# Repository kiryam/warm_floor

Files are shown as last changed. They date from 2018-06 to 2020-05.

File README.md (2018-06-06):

# Absolutely no warranty USE ON YOUR OWN RISK

# About this project
This project I started when I finished my home lab in balcony of my house.
I found that it is very cold in december. I decided to install floor heater to make temperature comfortable,
but first attempt been wrong. I had very hot floor. I decided to make floor heater with 5 zones (unformattly right now device have support for 6 zones)

# Hardware
## High voltage module
todo

## Logic module
todo

## Controller module
todo

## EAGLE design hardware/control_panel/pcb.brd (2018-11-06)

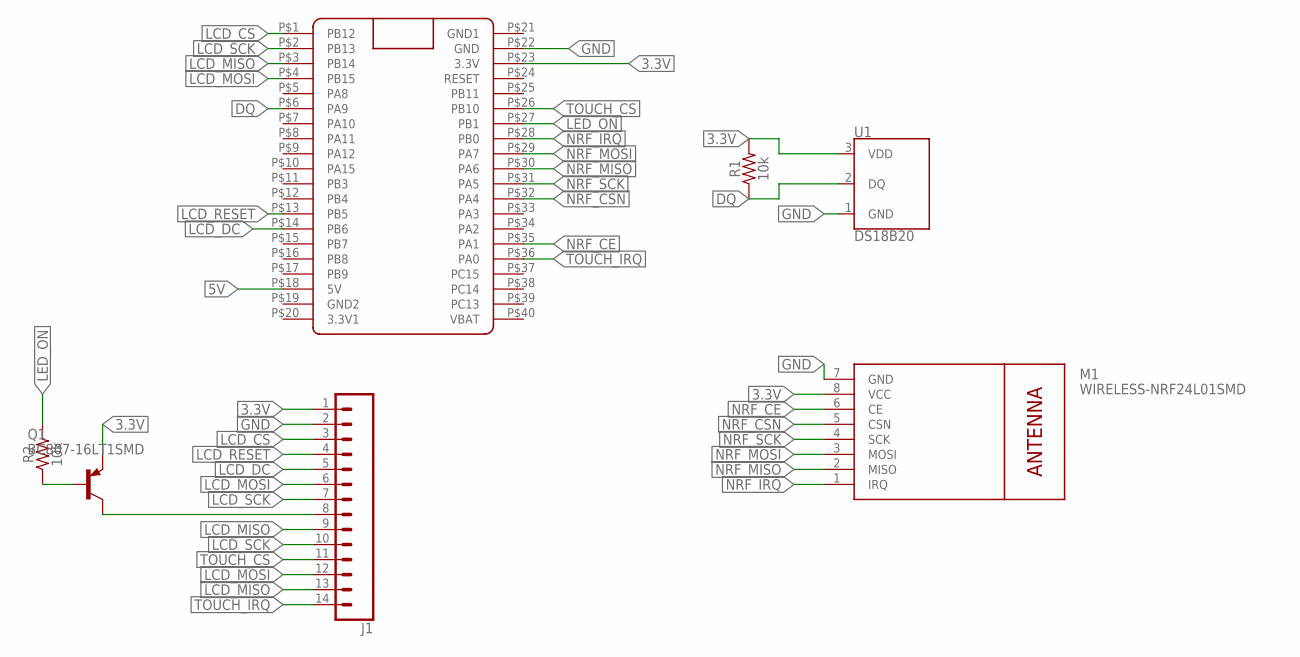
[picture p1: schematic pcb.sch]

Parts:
J1: CONN_14; 1X14
M1: WIRELESS-NRF24L01SMD; WIRELESS-NRF24L01-SMD
Q1: BC807-16LT1SMD; SOT23-BEC
R1, R2: 10k; 0603
U1: DS18B20; TO-92-AMMO
U$1: BLUE_PILL

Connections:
3.3V: J1.1, M1.8 (VCC), Q1.E, R1.2, U1.3 (VDD), U$1.P$23 (3.3V)
5V: U$1.P$18 (5V)
DQ: R1.1, U1.2 (DQ), U$1.P$6 (PA9)
GND: J1.2, M1.7 (GND), U1.1 (GND), U$1.P$22 (GND)
GND1: U$1.P$21 (GND1)
LCD_CS: J1.3, U$1.P$1 (PB12)
LCD_DC: J1.5, U$1.P$14 (PB6)
LCD_MISO: J1.9, J1.13, U$1.P$3 (PB14)
LCD_MOSI: J1.6, J1.12, U$1.P$4 (PB15)
LCD_RESET: J1.4, U$1.P$13 (PB5)
LCD_SCK: J1.7, J1.10, U$1.P$2 (PB13)
LED_ON: R2.2, U$1.P$27 (PB1)
unnamed: Q1.B, R2.1
unnamed: J1.8, Q1.C
NRF_CE: M1.6 (CE), U$1.P$35 (PA1)
NRF_CSN: M1.5 (CSN), U$1.P$32 (PA4)
NRF_IRQ: M1.1 (IRQ), U$1.P$28 (PB0)
NRF_MISO: M1.2 (MISO), U$1.P$30 (PA6)
NRF_MOSI: M1.3 (MOSI), U$1.P$29 (PA7)
NRF_SCK: M1.4 (SCK), U$1.P$31 (PA5)
TOUCH_CS: J1.11, U$1.P$26 (PB10)
TOUCH_IRQ: J1.14, U$1.P$36 (PA0)

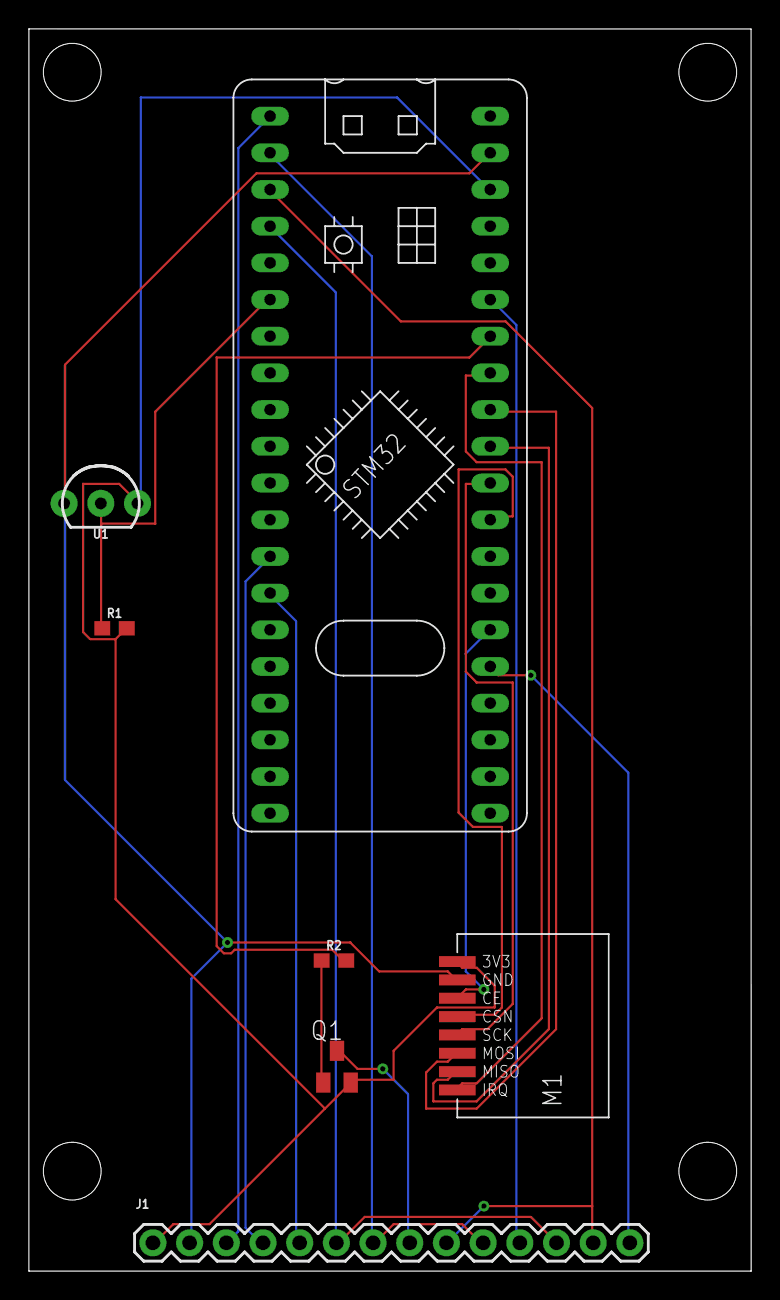
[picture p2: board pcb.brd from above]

Board: 2 copper layers, 50.0 x 86.0 mm, 7 parts (0 on the bottom side), 20 nets.

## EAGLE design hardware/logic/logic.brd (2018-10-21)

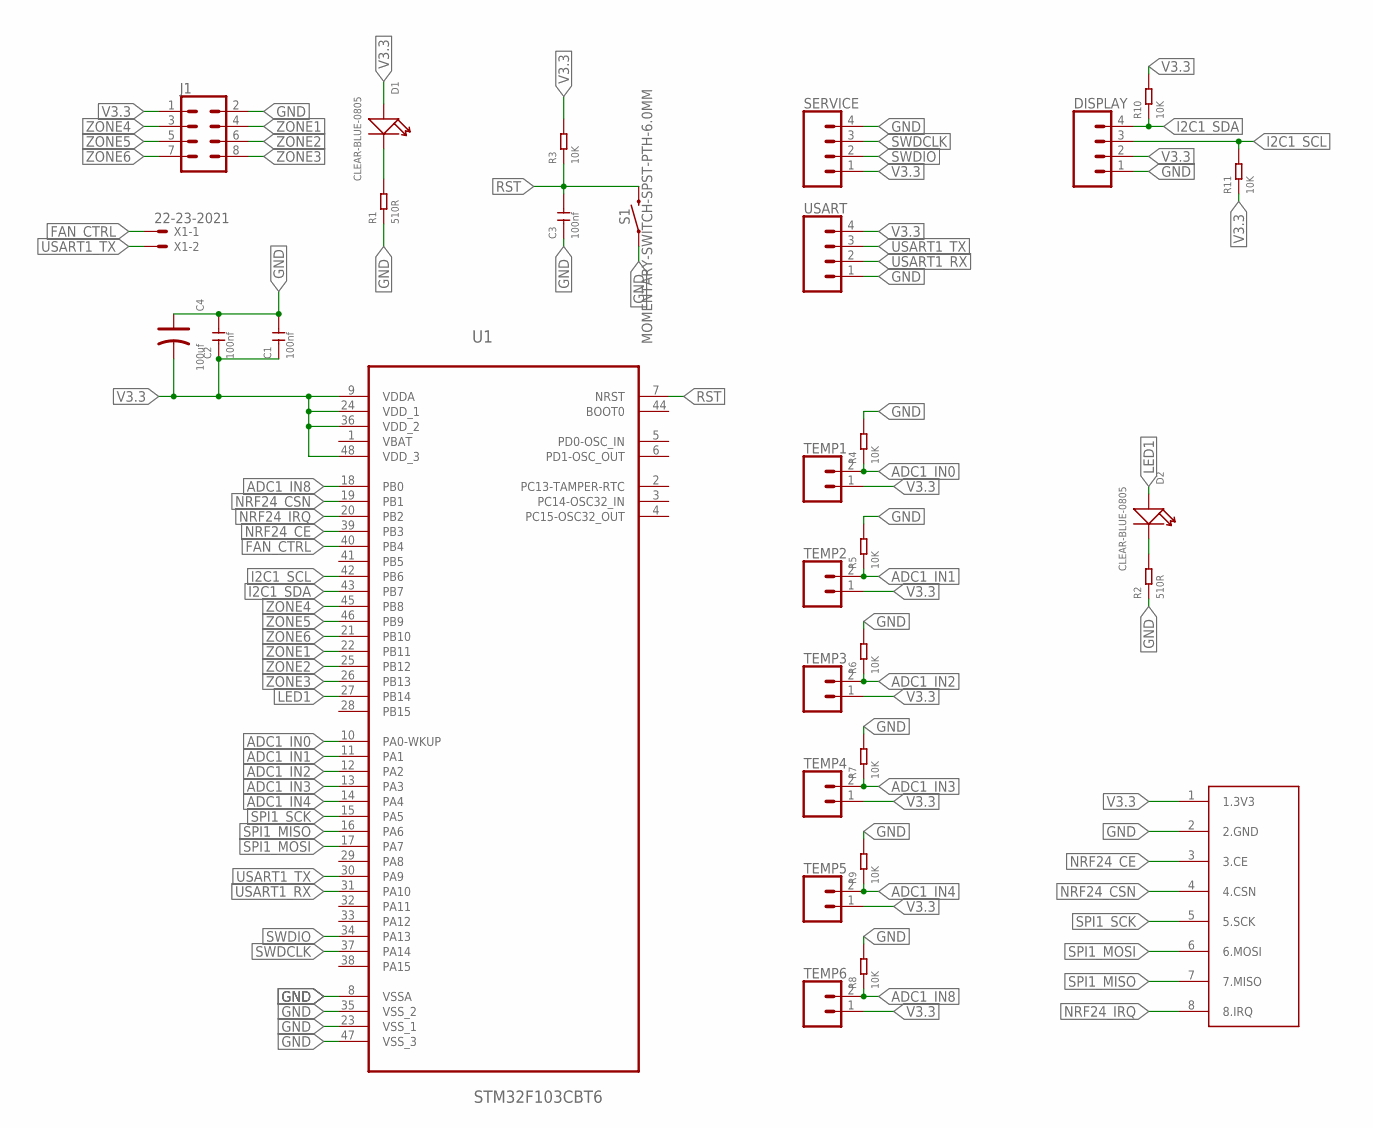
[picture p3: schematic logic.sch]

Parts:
C1, C2, C3: 100nf; C0805
C4: 100uf; AVX-B
D1, D2: CLEAR-BLUE-0805; LED-0805
DISPLAY: CONN_04; 1X04
J1: CONN_04X2; 2X4
R1, R2: 510R; R0603
R3, R4, R5, R6, R7, R8, R9, R10, R11: 10K; R0805
S1: MOMENTARY-SWITCH-SPST-PTH-6.0MM; TACTILE_SWITCH_PTH_6.0MM
SERVICE: CONN_04; 1X04
TEMP1, TEMP2, TEMP3, TEMP4, TEMP5, TEMP6: CONN_02; 1X02
U1: STM32F103CBT6; QFP50P900X900X160-48N
U$2: NRF24L01+
USART: CONN_04; 1X04
X1: 22-23-2021

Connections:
ADC1_IN0: R4.1, TEMP1.2, U1.10 (PA0-WKUP)
ADC1_IN1: R5.1, TEMP2.2, U1.11 (PA1)
ADC1_IN2: R6.1, TEMP3.2, U1.12 (PA2)
ADC1_IN3: R7.1, TEMP4.2, U1.13 (PA3)
ADC1_IN4: R9.1, TEMP5.2, U1.14 (PA4)
ADC1_IN8: R8.1, TEMP6.2, U1.18 (PB0)
FAN_CTRL: U1.40 (PB4), X1.1
GND: C1.2, C2.2, C3.1, C4.+, DISPLAY.1, J1.2, R1.1, R2.1, R4.2, R5.2, R6.2, R7.2, R8.2, R9.2, S1.1, SERVICE.4, U1.8 (VSSA), U1.23 (VSS_1), U1.35 (VSS_2), U1.47 (VSS_3), U$2.2 (2.GND), USART.1
I2C1_SCL: DISPLAY.3, R11.2, U1.42 (PB6)
I2C1_SDA: DISPLAY.4, R10.1, U1.43 (PB7)
LED1: D2.+, U1.27 (PB14)
unnamed: D1.-, R1.2
unnamed: D2.-, R2.2
NRF24_CE: U1.39 (PB3), U$2.3 (3.CE)
NRF24_CSN: U1.19 (PB1), U$2.4 (4.CSN)
NRF24_IRQ: U1.20 (PB2), U$2.8 (8.IRQ)
PA11: U1.32 (PA11)
RST: C3.2, R3.1, S1.3 (2), U1.7 (NRST)
SPI1_MISO: U1.16 (PA6), U$2.7 (7.MISO)
SPI1_MOSI: U1.17 (PA7), U$2.6 (6.MOSI)
SPI1_SCK: U1.15 (PA5), U$2.5 (5.SCK)
SWDCLK: SERVICE.3, U1.37 (PA14)
SWDIO: SERVICE.2, U1.34 (PA13)
USART1_RX: U1.31 (PA10), USART.2
USART1_TX: U1.30 (PA9), USART.3, X1.2
V3.3: C1.1, C2.1, C4.-, D1.+, DISPLAY.2, J1.1, R3.2, R10.2, R11.1, SERVICE.1, TEMP1.1, TEMP2.1, TEMP3.1, TEMP4.1, TEMP5.1, TEMP6.1, U1.9 (VDDA), U1.24 (VDD_1), U1.36 (VDD_2), U1.48 (VDD_3), U$2.1 (1.3V3), USART.4
ZONE1: J1.4, U1.22 (PB11)
ZONE2: J1.6, U1.25 (PB12)
ZONE3: J1.8, U1.26 (PB13)
ZONE4: J1.3, U1.45 (PB8)
ZONE5: J1.5, U1.46 (PB9)
ZONE6: J1.7, U1.21 (PB10)

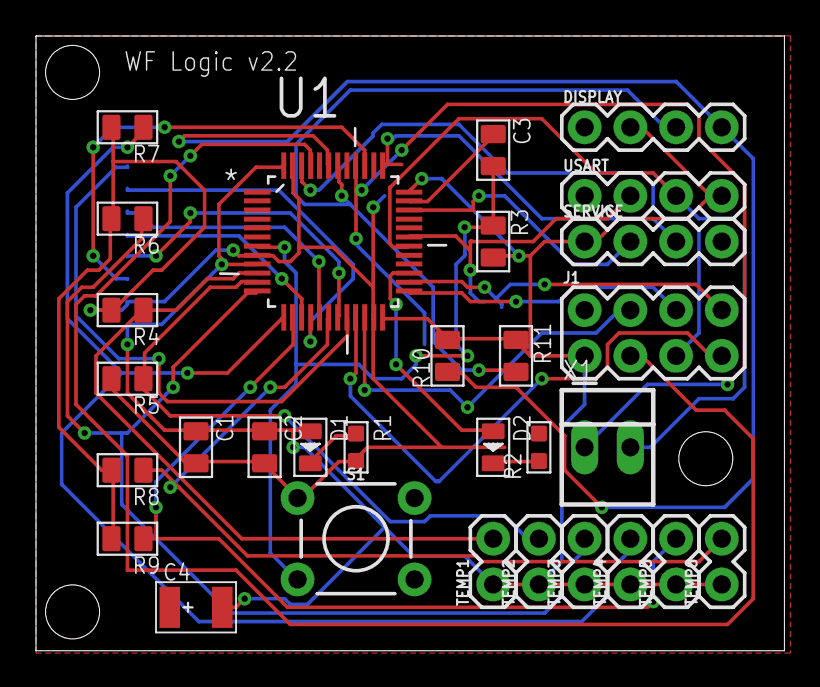
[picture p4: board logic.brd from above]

Board: 2 copper layers, 41.6 x 34.2 mm, 31 parts (1 on the bottom side), 31 nets.

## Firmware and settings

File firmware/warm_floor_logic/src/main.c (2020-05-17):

#include <stdio.h>
#include <stdlib.h>
#include "platform.h"

#include "diag/Trace.h"
#include "led.h"
#include "switch.h"
#include "serial.h"
#include "fan.h"
#ifdef DISPLAY
#include "display.h"
#endif
#include "radio.h"
#include "misc.h"
#include "main.h"

#include "libdproto.h"
#include "pb_decode.h"
#include "pb_encode.h"
#include "floor.pb.h"
#include "DS18B20.h"

#include "cmsis_os.h"
#include "timers.h"
#include "queue.h"

#pragma GCC diagnostic push
#pragma GCC diagnostic ignored "-Wunused-parameter"
#pragma GCC diagnostic ignored "-Wmissing-declarations"
#pragma GCC diagnostic ignored "-Wreturn-type"

Core core;

#define WATCHDOG_ENABLED
#define INTERNAL_TEMP_SENSOR
//#define SERIAL_DEBUG
#define USE_DEBUG_BKP_REGISTER


#define MIN_TEMP -30
#define MAX_TEMP 80
#define MAX_INSIDE_TEMP 80
#define FAN_ON_TEMP 50
#define MAX_ZONES_AT_THE_MOMENT 5

#define RADION_MAX_PACKETS_IN_MESSAGE 10
#define RADIO_BUFFER_SIZE RADION_MAX_PACKETS_IN_MESSAGE*NRF_PAYLOAD_LENGTH

static uint8_t magic_sequence[DPROTO_MAGIC_SEC_LEN] = {4, 8, 15, 16};
static uint8_t radio_buffer[RADIO_BUFFER_SIZE];
static uint8_t pb_buffer[1024];
static uint8_t zones_on;

#if configUSE_TIMERS == 1
static TimerHandle_t fanTimer;
static void fanTimerCallback( TimerHandle_t xExpiredTimer );
#endif

#ifdef DISPLAY
void DisplayRenderTask(void const * argument);
#endif
void MessageReadTask(void const * argument);
void SwitchStateTask(void const * argument);
void SendStateTask(void const * argument);

void USART1_IRQHandler() {
	if(USART_GetITStatus(USART1, USART_IT_RXNE) != RESET) {
		USART_ClearITPendingBit(USART1, USART_IT_RXNE);
		Serial_Callback callback;
		callback.dev = (void*)&core.usart1;
		callback.c = (char) USART_ReceiveData(USART1);
		core.usart1.RX_HANDLER((void*)&callback);
	}
}

#ifdef USE_DEBUG_BKP_REGISTER
	#define DEBUG_BKP_RESET_STATE 0
	#define DEBUG_BKP_RESET_BECAUSE_OF_MAX_TEMP 1
	void Debug_BKP_SET(uint16_t value) {
		uint16_t val;
		val = BKP_ReadBackupRegister(BKP_DR1);
		val |= val;
		BKP_WriteBackupRegister(BKP_DR1, val);
	}
#endif

void Led1_Init(LED_dev* led){
	RCC_APB2PeriphClockCmd(RCC_APB2Periph_GPIOB, ENABLE);
	led->LED_GPIOx = GPIOB;
	led->LED_PIN = GPIO_Pin_14;
	LED_Init(led);
}

void Switch1_Init(Switch_dev* swtch){
	RCC_APB2PeriphClockCmd(RCC_APB2Periph_GPIOB, ENABLE);
	swtch->Switch_GPIOx = GPIOB;
	swtch->Switch_PIN = GPIO_Pin_11;
	swtch->start_on = false;
	Switch_Init(swtch);
}

void Switch2_Init(Switch_dev* swtch){
	RCC_APB2PeriphClockCmd(RCC_APB2Periph_GPIOB, ENABLE);
	swtch->Switch_GPIOx = GPIOB;
	swtch->Switch_PIN = GPIO_Pin_12;
	swtch->start_on = false;
	Switch_Init(swtch);
}

void Switch3_Init(Switch_dev* swtch){
	RCC_APB2PeriphClockCmd(RCC_APB2Periph_GPIOB, ENABLE);
	swtch->Switch_GPIOx = GPIOB;
	swtch->Switch_PIN = GPIO_Pin_13;
	swtch->start_on = false;
	Switch_Init(swtch);
}

void Switch4_Init(Switch_dev* swtch){
	RCC_APB2PeriphClockCmd(RCC_APB2Periph_GPIOB, ENABLE);
	swtch->Switch_GPIOx = GPIOB;
	swtch->Switch_PIN = GPIO_Pin_8;
	swtch->start_on = false;
	Switch_Init(swtch);
}

void Switch5_Init(Switch_dev* swtch){
	RCC_APB2PeriphClockCmd(RCC_APB2Periph_GPIOB, ENABLE);
	swtch->Switch_GPIOx = GPIOB;
	swtch->Switch_PIN = GPIO_Pin_9;
	swtch->start_on = false;
	Switch_Init(swtch);
}

void Switch6_Init(Switch_dev* swtch){
	RCC_APB2PeriphClockCmd(RCC_APB2Periph_GPIOB, ENABLE);
	swtch->Switch_GPIOx = GPIOB;
	swtch->Switch_PIN = GPIO_Pin_10;
	swtch->start_on = false;
	Switch_Init(swtch);
}

void Serial1_Init(SERIAL_dev* usart){
	RCC_APB2PeriphClockCmd(RCC_APB2Periph_GPIOA, ENABLE);
	RCC_APB2PeriphClockCmd(RCC_APB2Periph_USART1, ENABLE);

	GPIO_PinRemapConfig(GPIO_Remap_USART1, DISABLE);

	usart->usart->Init.USART_BaudRate = 115200;
	usart->usart->Instance = USART1;
	usart->USART_TX_GPIOx = GPIOA;
	usart->USART_TX_PIN = GPIO_Pin_9;

	usart->USART_RX_GPIOx = GPIOA;
	usart->USART_RX_PIN = GPIO_Pin_10;
	Serial_Init(usart);

	NVIC_InitTypeDef NVIC_InitStructure;
	NVIC_InitStructure.NVIC_IRQChannel = USART1_IRQn;
	NVIC_InitStructure.NVIC_IRQChannelPreemptionPriority = 1;
	NVIC_InitStructure.NVIC_IRQChannelSubPriority = 0;
	NVIC_InitStructure.NVIC_IRQChannelCmd = ENABLE;
	NVIC_Init(&NVIC_InitStructure);

	NVIC_EnableIRQ(USART1_IRQn);
}

bool is_timer_started = false;

#ifdef DISPLAY
void Display1_Init(Display* display){
	Display_Init(display);
}
#endif

void DS18B20_Init(){
	if(ds18b20_init() == 0)  {
		//ERROR NO SENSORS
	}
}

unsigned char RTC_Init(void){
	RCC_APB1PeriphClockCmd(RCC_APB1Periph_PWR | RCC_APB1Periph_BKP, ENABLE);
	PWR_BackupAccessCmd(ENABLE);

	if ((RCC->BDCR & RCC_BDCR_RTCEN) != RCC_BDCR_RTCEN) {
		// Сброс данных в резервной области
		RCC_BackupResetCmd(ENABLE);
		RCC_BackupResetCmd(DISABLE);

		RCC_LSICmd(ENABLE);
		while((RCC->CSR & RCC_CSR_LSIRDY) == 0);

		RCC_RTCCLKConfig(RCC_RTCCLKSource_LSI);
		RTC_SetPrescaler(40000);

		RCC_RTCCLKCmd(ENABLE);
		RTC_WaitForSynchro();
		return 1;
	}
	return 0;
}

int main(int argc, char* argv[]) {
	SysTick_Init();
	NVIC_SetPriority(SysTick_IRQn, 15);

	Fan1_Init();

	Switch1_Init(&core.switches[0]);
	Switch2_Init(&core.switches[1]);
	Switch3_Init(&core.switches[2]);
	Switch4_Init(&core.switches[3]);
	Switch5_Init(&core.switches[4]);
	Switch6_Init(&core.switches[5]);

	Led1_Init(&core.led1);

	#ifdef USE_DEBUG_BKP_REGISTER
	RCC_APB1PeriphClockCmd(RCC_APB1Periph_PWR | RCC_APB1Periph_BKP, ENABLE);
	RCC_BackupResetCmd(ENABLE);

	Blink_times(5, 30);
	delay_nms(1000);
	uint16_t reload_counter = BKP_ReadBackupRegister(BKP_DR1);
	Blink_times(reload_counter, 500);
	delay_nms(1000);
	Blink_times(10, 30);
	Debug_BKP_SET(DEBUG_BKP_RESET_STATE); // reset
	#endif

	Fan1_On();

	#ifdef INTERNAL_TEMP_SENSOR
	DS18B20_Init();
	ds18b20_start_convert();

	delay_nms(1000);
	core.temp1 = (int32_t)ds18b20_get_temp(0);

	Blink_times(core.temp1/10, 500);
	#endif

	#ifdef WATCHDOG_ENABLED
	IWDG_WriteAccessCmd(IWDG_WriteAccess_Enable);
	IWDG_SetPrescaler(IWDG_Prescaler_256);
	IWDG_SetReload(0x0FFF);//This parameter must be a number between 0 and 0x0FFF.
	IWDG_ReloadCounter();
	IWDG_Enable();
	#endif

	RTC_Init();

	#ifdef SERIAL_DEBUG
	USART_HandleTypeDef usart_usart;
	core.usart1.usart = &usart_usart;
	Serial1_Init(&core.usart1);
	Serial_Send_Str(&core.usart1, "Initializing\r\n");
	#endif

	#ifdef DISPLAY
	Display1_Init(&core.display);
	//Serial_Send_Str(&core.usart1, "Display init ok\r\n");
	#endif

	Radio_Init(&core.radio1);
	DEBUG(&core.usart1, "Radio init ok\r\n");

	Thermometer_Init(&core.thermometers);
	DEBUG(&core.usart1, "Thermometer init ok\r\n");

	core.radio_queue = xQueueCreate(32, sizeof(uint8_t));
	DEBUG(&core.usart1, "Radio queue initialized\r\n");

	#if configUSE_TIMERS == 1
	fanTimer = xTimerCreate( "fanTimer", 5000/portTICK_RATE_MS, pdFALSE, ( void * )0, fanTimerCallback );
	xTimerStart( fanTimer, 0 );
	#endif

	osThreadId thread;
	osThreadDef(switchStateTask, SwitchStateTask, osPriorityHigh, 0, 512);
	thread = osThreadCreate(osThread(switchStateTask), NULL);

	if(thread == NULL){
		DEBUG(&core.usart1, "Failed to create switchStateTask\r\n");
	}

	osThreadDef(messageReadTask, MessageReadTask, osPriorityNormal, 0, configMINIMAL_STACK_SIZE);
	osThreadCreate(osThread(messageReadTask), NULL);

	osThreadDef(sendStateTask, SendStateTask, osPriorityNormal, 0, configMINIMAL_STACK_SIZE);
	osThreadCreate(osThread(sendStateTask), NULL);

	DEBUG(&core.usart1, "Tasks created\r\n");

	#ifdef DISPLAY
	osThreadDef(displayRenderTask, DisplayRenderTask, osPriorityLow, 0, configMINIMAL_STACK_SIZE);
	osThreadCreate(osThread(displayRenderTask), NULL);
	#endif

	osKernelStart();
	DEBUG(&core.usart1, "Kernel start done\r\n");
	while(1){}
}

#if configUSE_TIMERS == 1
static void fanTimerCallback( TimerHandle_t xExpiredTimer ) {
	Fan1_Off();
	xTimerStop( xExpiredTimer, (TickType_t) 10 );
}
#endif

void MessageReadTask(void const * argument){
	DEBUG(&core.usart1, "MessageReadTask started\r\n");
	uint32_t buffer_pos = 0;
	uint32_t length=0;
	uint8_t data=0;
	for(;;){
		if( xQueueReceive( (xQueueHandle)core.radio_queue, &( data ), ( TickType_t ) 100 ) ) {
			DEBUG(&core.usart1, "Reading message from radio_queue\r\n");
			if( buffer_pos >= RADIO_BUFFER_SIZE ) {
				buffer_pos=0;
				length = 0;
				//core.messages_failed++;
				break;
			}

			int result = dproto_process_byte(radio_buffer, &length, magic_sequence, data, buffer_pos++);

			if (result == -1) { // decode error
				buffer_pos=0;
				length = 0;
				//core.messages_failed++;
			} else if (result == 1 ){ // read message done
				pb_istream_t stream = pb_istream_from_buffer(radio_buffer, length);

				//core.messages_readed++;
				buffer_pos=0;
				length = 0;

				pb_decode(&stream, TempSet_fields, &core.tempSet);
				core.lastTempSet = RTC_GetCounter();
				LED_On(&core.led1);
				osDelay(100);
				LED_Off(&core.led1);
			}
		}
	}
}

#ifdef DISPLAY
void DisplayRenderTask(void const * argument){
	 for(;;) {
		SSD1306_Fill(SSD1306_COLOR_BLACK);

		Display_DrawTemp(&core.display, core.tempSet.temp);
		char message[16]={0};
		sprintf(message, "Recv: %d", core.packets_rx);
		Display_DrawMessage(&core.display, 64, message);

		sprintf(message, "Read: %d Failed: %d", core.messages_readed, core.messages_failed);
		Display_DrawMessage(&core.display, 50, message);

		SSD1306_UpdateScreen();
		osDelay(100);
	  }
}
#endif


void SwitchStateTask(void const * argument){
	DEBUG(&core.usart1, "SwitchStateTask started\r\n");
	for(;;) {
		DEBUG(&core.usart1, "SwitchStateTask\r\n");

		core.tempActual.zone_1 = Thermometer_GetValue(&core.thermometers, 0);
		core.tempActual.zone_2 = Thermometer_GetValue(&core.thermometers, 1);
		core.tempActual.zone_3 = Thermometer_GetValue(&core.thermometers, 2);
		core.tempActual.zone_4 = Thermometer_GetValue(&core.thermometers, 3);
		core.tempActual.zone_5 = Thermometer_GetValue(&core.thermometers, 4);
	//	core.tempActual.zone_6 = Thermometer_GetValue(&core.thermometers, 5);

		#ifdef INTERNAL_TEMP_SENSOR
		core.temp1 = (int32_t)ds18b20_get_temp(0);
		core.temp2 = (int32_t)ds18b20_get_temp(1);
		ds18b20_start_convert();
		#endif

		#if configUSE_TIMERS == 0
		int8_t fan_value = ((max(core.temp1, core.temp2)-FAN_MIN_DEGREE)*100/(FAN_MAX_DEGREE-FAN_MIN_DEGREE));
		if (fan_value > 0) {
			Fan1_Set(fan_value);
		} else {
			Fan1_Set(0);
		}
		#else
		Fan1_On(); // always on
		#endif

		if( core.temp1 > MAX_INSIDE_TEMP || core.temp2 > MAX_INSIDE_TEMP || core.tempActual.zone_2 > MAX_TEMP || core.tempActual.zone_3 > MAX_TEMP
				|| core.tempActual.zone_4 > MAX_TEMP || core.tempActual.zone_5 > MAX_TEMP /* || core.tempActual.zone_6 > MAX_TEMP*/) {

			#ifdef USE_DEBUG_BKP_REGISTER
			Debug_BKP_SET(DEBUG_BKP_RESET_BECAUSE_OF_MAX_TEMP); // reset
			#endif
			NVIC_SystemReset();
		}

		#ifdef INTERNAL_TEMP_SENSOR
		bool can_heat = false;

		int32_t lastTempDiff = RTC_GetCounter()-core.lastTempSet;
		if ( (core.temp1 > -40 && core.temp1 < 60) && (core.temp2 > -40 && core.temp2 < 60) && abs(core.temp1 - core.temp2) < 20 && lastTempDiff < MAX_TIME_SINCE_TEMP_SET ) { // check inside temp
			can_heat = true;
		}
		#else
		bool can_heat = true;
		#endif

		zones_on=0;

		if(core.tempSet.zone_1 > core.tempActual.zone_1 && core.tempActual.zone_1 > MIN_TEMP && can_heat && zones_on < MAX_ZONES_AT_THE_MOMENT ) {
			Switch_On(&core.switches[0]);
			zones_on++;
		} else {
			Switch_Off(&core.switches[0]);
		}

		if(core.tempSet.zone_2 > core.tempActual.zone_2 && core.tempActual.zone_2 > MIN_TEMP && can_heat && zones_on < MAX_ZONES_AT_THE_MOMENT ) {
			Switch_On(&core.switches[1]);
			zones_on++;
		} else {
			Switch_Off(&core.switches[1]);
		}

		if(core.tempSet.zone_3 > core.tempActual.zone_3 && core.tempActual.zone_3 > MIN_TEMP && can_heat && zones_on < MAX_ZONES_AT_THE_MOMENT ) {
			Switch_On(&core.switches[2]);
			zones_on++;
		} else {
			Switch_Off(&core.switches[2]);
		}

		if(core.tempSet.zone_4 > core.tempActual.zone_4 && core.tempActual.zone_4 > MIN_TEMP && can_heat && zones_on < MAX_ZONES_AT_THE_MOMENT) {
			Switch_On(&core.switches[3]);
			zones_on++;
		} else {
			Switch_Off(&core.switches[3]);
		}

		if(core.tempSet.zone_5 > core.tempActual.zone_5 && core.tempActual.zone_5 > MIN_TEMP && can_heat && zones_on < MAX_ZONES_AT_THE_MOMENT) {
			Switch_On(&core.switches[4]);
			zones_on++;
		} else {
			Switch_Off(&core.switches[4]);
		}

		if(core.tempSet.zone_6 > core.tempActual.zone_6 && core.tempActual.zone_6 > MIN_TEMP && can_heat && zones_on < MAX_ZONES_AT_THE_MOMENT) {
			Switch_On(&core.switches[5]);
			zones_on++;
		} else {
			Switch_Off(&core.switches[5]);
		}

		#ifdef WATCHDOG_ENABLED
			IWDG_ReloadCounter();
		#endif
		osDelay(100);
	  }
}

void SendStateTask(void const * argument){
	DEBUG(&core.usart1, "SendStateTask started\r\n");
	for(;;){
		DEBUG(&core.usart1, "SendStateTask\r\n");

		State state = State_init_zero;
		state.temp1 = core.temp1;
		state.temp2 = core.temp2;
		state.tempSet = core.tempSet;
		state.tempActual = core.tempActual;

		pb_ostream_t stream = pb_ostream_from_buffer(pb_buffer, sizeof(pb_buffer));
		pb_encode(&stream, State_fields, &state);
		Radio_Send(&core.radio1, pb_buffer, stream.bytes_written);
		LED_Off(&core.led1);

		DEBUG(&core.usart1, "DONE SendStateTask\r\n");
		osDelay(2000);
	}
}

void _Error_Handler(char * file, int line){
	DEBUG(&core.usart1, "_Error_Handler\r\n");
	while(1){}
}

#pragma GCC diagnostic pop

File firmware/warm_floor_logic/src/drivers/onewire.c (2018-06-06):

#include "onewire.h"
#include "platform.h"

#define OW_USART 		USART1
#define OW_DMA_CH_RX 	DMA1_Channel5
#define OW_DMA_CH_TX 	DMA1_Channel4
#define OW_DMA_FLAG		DMA1_FLAG_TC5
#define OW_PIN          GPIO_Pin_9

uint8_t ow_buf[8];

#define OW_0	        0x00
#define OW_1	        0xff
#define OW_R_1	        0xff

#define OW_CMD_SEARCH   0xf0
#define OW_CMD_MATCH    0x55

static uint8_t LastDiscrepancy;       /*!< Search private */
static uint8_t LastDeviceFlag;        /*!< Search private */
static uint8_t DeviceID;
static uint8_t ROM_NO[8];

static void OW_toBits(uint8_t ow_byte, uint8_t *ow_bits) {
	uint8_t i;
	for (i = 0; i < 8; i++) {
		if (ow_byte & 0x01) {
			*ow_bits = OW_1;
		} else {
			*ow_bits = OW_0;
		}
		ow_bits++;
		ow_byte = ow_byte >> 1;
	}
}

static uint8_t OW_toByte(uint8_t *ow_bits) {
	uint8_t ow_byte, i;
	ow_byte = 0;
	for (i = 0; i < 8; i++) {
		ow_byte = ow_byte >> 1;
		if (*ow_bits == OW_R_1) {
			ow_byte |= 0x80;
		}
		ow_bits++;
	}
	return ow_byte;
}

uint8_t OW_Init(void) {
    RCC_AHBPeriphClockCmd(RCC_AHBPeriph_DMA1, ENABLE);
    RCC_APB2PeriphClockCmd(RCC_APB2Periph_USART1 | RCC_APB2Periph_GPIOA | RCC_APB2Periph_AFIO, ENABLE);

	GPIO_InitTypeDef GPIO_InitStruct;
	USART_InitTypeDef USART_InitStructure;

    GPIO_InitStruct.GPIO_Pin = OW_PIN;
    GPIO_InitStruct.GPIO_Mode = GPIO_Mode_AF_OD;
    GPIO_InitStruct.GPIO_Speed = GPIO_Speed_50MHz;

    GPIO_Init(GPIOA, &GPIO_InitStruct);

	USART_InitStructure.USART_BaudRate = 115200;
	USART_InitStructure.USART_WordLength = USART_WordLength_8b;
	USART_InitStructure.USART_StopBits = USART_StopBits_1;
	USART_InitStructure.USART_Parity = USART_Parity_No;
	USART_InitStructure.USART_HardwareFlowControl = USART_HardwareFlowControl_None;
	USART_InitStructure.USART_Mode = USART_Mode_Tx | USART_Mode_Rx;

	USART_Init(OW_USART, &USART_InitStructure);
	USART_Cmd(OW_USART, ENABLE);

    USART_HalfDuplexCmd(OW_USART, ENABLE);

    if(GPIO_ReadInputDataBit(GPIOA, OW_PIN) == 0) {
        return OW_ERROR;
    }

	return OW_OK;
}

uint8_t OW_Reset(void) {
	uint8_t ow_presence;
	USART_InitTypeDef USART_InitStructure;

	USART_InitStructure.USART_BaudRate = 9600;
	USART_InitStructure.USART_WordLength = USART_WordLength_8b;
	USART_InitStructure.USART_StopBits = USART_StopBits_1;
	USART_InitStructure.USART_Parity = USART_Parity_No;
	USART_InitStructure.USART_HardwareFlowControl = USART_HardwareFlowControl_None;
	USART_InitStructure.USART_Mode = USART_Mode_Tx | USART_Mode_Rx;
	USART_Init(OW_USART, &USART_InitStructure);

	USART_ClearFlag(OW_USART, USART_FLAG_TC);
	USART_SendData(OW_USART, 0xf0);
	while (USART_GetFlagStatus(OW_USART, USART_FLAG_TC) == RESET);

	ow_presence = USART_ReceiveData(OW_USART);

	USART_InitStructure.USART_BaudRate = 115200;
	USART_InitStructure.USART_WordLength = USART_WordLength_8b;
	USART_InitStructure.USART_StopBits = USART_StopBits_1;
	USART_InitStructure.USART_Parity = USART_Parity_No;
	USART_InitStructure.USART_HardwareFlowControl = USART_HardwareFlowControl_None;
	USART_InitStructure.USART_Mode = USART_Mode_Tx | USART_Mode_Rx;
	USART_Init(OW_USART, &USART_InitStructure);

	if (ow_presence != 0xf0) {
		return OW_OK;
	}

	return OW_NO_DEVICE;
}

uint8_t OW_Send(uint8_t sendReset, uint8_t *command, uint8_t cLen, uint8_t *data, uint8_t dLen, uint8_t readStart) {
	if (sendReset == OW_SEND_RESET) {
		if (OW_Reset() == OW_NO_DEVICE) {
			return OW_NO_DEVICE;
		}
	}

	while (cLen > 0) {
		OW_toBits(*command, ow_buf);
		command++;
		cLen--;

		DMA_InitTypeDef DMA_InitStructure;

		DMA_DeInit(OW_DMA_CH_RX);
		DMA_InitStructure.DMA_PeripheralBaseAddr = (uint32_t) &(OW_USART->DR);
		DMA_InitStructure.DMA_MemoryBaseAddr = (uint32_t) ow_buf;
		DMA_InitStructure.DMA_DIR = DMA_DIR_PeripheralSRC;
		DMA_InitStructure.DMA_BufferSize = 8;
		DMA_InitStructure.DMA_PeripheralInc = DMA_PeripheralInc_Disable;
		DMA_InitStructure.DMA_MemoryInc = DMA_MemoryInc_Enable;
		DMA_InitStructure.DMA_PeripheralDataSize = DMA_PeripheralDataSize_Byte;
		DMA_InitStructure.DMA_MemoryDataSize = DMA_MemoryDataSize_Byte;
		DMA_InitStructure.DMA_Mode = DMA_Mode_Normal;
		DMA_InitStructure.DMA_Priority = DMA_Priority_Low;
		DMA_InitStructure.DMA_M2M = DMA_M2M_Disable;
		DMA_Init(OW_DMA_CH_RX, &DMA_InitStructure);

		DMA_DeInit(OW_DMA_CH_TX);
		DMA_InitStructure.DMA_PeripheralBaseAddr = (uint32_t) &(OW_USART->DR);
		DMA_InitStructure.DMA_MemoryBaseAddr = (uint32_t) ow_buf;
		DMA_InitStructure.DMA_DIR = DMA_DIR_PeripheralDST;
		DMA_InitStructure.DMA_BufferSize = 8;
		DMA_InitStructure.DMA_PeripheralInc = DMA_PeripheralInc_Disable;
		DMA_InitStructure.DMA_MemoryInc = DMA_MemoryInc_Enable;
		DMA_InitStructure.DMA_PeripheralDataSize = DMA_PeripheralDataSize_Byte;
		DMA_InitStructure.DMA_MemoryDataSize = DMA_MemoryDataSize_Byte;
		DMA_InitStructure.DMA_Mode = DMA_Mode_Normal;
		DMA_InitStructure.DMA_Priority = DMA_Priority_Low;
		DMA_InitStructure.DMA_M2M = DMA_M2M_Disable;
		DMA_Init(OW_DMA_CH_TX, &DMA_InitStructure);

		USART_ClearFlag(OW_USART, USART_FLAG_RXNE | USART_FLAG_TC); // | USART_FLAG_TXE
		USART_DMACmd(OW_USART, USART_DMAReq_Tx | USART_DMAReq_Rx, ENABLE);
		DMA_Cmd(OW_DMA_CH_RX, ENABLE);
		DMA_Cmd(OW_DMA_CH_TX, ENABLE);

		while (DMA_GetFlagStatus(OW_DMA_FLAG) == RESET) {
			asm("nop");
		}

		DMA_Cmd(OW_DMA_CH_TX, DISABLE);
		DMA_Cmd(OW_DMA_CH_RX, DISABLE);
		USART_DMACmd(OW_USART, USART_DMAReq_Tx | USART_DMAReq_Rx, DISABLE);

        if (readStart == 0 && dLen > 0) {
			*data = OW_toByte(ow_buf);
			data++;
			dLen--;
		} else {
			if (readStart != OW_NO_READ) {
				readStart--;
			}
		}
	}

	return OW_OK;
}
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

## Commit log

2018-06-06 fusion sync
    [hw.brd, logic.brd]
2018-09-04 fixes in logic board. now support 6 channels. add debug
    [logic.brd, logic.sch]
2018-10-21 logic version 2.2
    [logic.brd, logic.sch]
2018-10-26 change MCP1703 to LM1117 800mah add change
2018-11-06 pww for fan. control_panel pcb
    [pcb.brd, pcb.sch]
2019-03-10 soft pwm tuning for fan
2020-05-17 add safety feature turn off heaters if not commands in 10 minutes

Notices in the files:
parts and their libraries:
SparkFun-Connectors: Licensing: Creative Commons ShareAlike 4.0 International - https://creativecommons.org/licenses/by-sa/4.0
